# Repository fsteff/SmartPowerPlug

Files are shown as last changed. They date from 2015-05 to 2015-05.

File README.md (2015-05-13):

# SmartPowerPlug
A Raspberry PI based power plug that measures the energy.
It is able to turn on/off the power if necessary, based on a shell script to be highly customizeable.

The webinterface displays the measured values on an interactive graph (using Rickshaw).

------------------------------------------------------------------------
SOFTWARE:
------------------------------------------------------------------------
Needed programs:
 - Apache 2 (or a similar webserver)
 - php5 and php-cli
 - php5-sqlite
 - SQLite3

PHP Dependencies:
 - PhpSerial
 - System_Daemon
 
JS Dependencies:
 - Rickshaw
 - D3
 - JQuery
 - JQuery UI
 - Menumaker

All the dependencies are included in the source.

------------------------------------------------------------------------
HARDWARE:
------------------------------------------------------------------------
The energy measurement is based on the MCP39F501, which communciates over RS485.

------------------------------------------------------------------------
Known issues:
------------------------------------------------------------------------
- After a reboot the serial (uart) has to be opened by an other program - if this is not the case, the raspberry answers with some rubbish sequences...
- The calibration of the MCP39F501 is invalid - maybe there is a problem with the print.

You can download a preinstalled raspbian image here:
https://mega.co.nz/#F!rpBVlAKI!rYRUqPWmyS1goKNWMSgLuQ

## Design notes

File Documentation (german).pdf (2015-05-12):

Höhere Technische Bundeslehranstalt Steyr
Schlüsselhofgasse 63
4400 Steyr / Austria
Elektronik und Technische Informatik
+43 7252 72914 • www.htl-steyr.ac.at • office@htl-steyr.ac.at

# Smart Plug

Die intelligente Steckdose

## 1. Inhaltsverzeichnis

Elektronik und Technische Informatik
+43 7252 72914 • www.htl-steyr.ac.at • office@htl-steyr.ac.at

## 2. Angabe

Die intelligente Steckdose dient dazu, Strom zu sparen und somit den Stromverbrauch zu senken. Ziel ist es, den Benutzer die einzelnen Stromfresser bzw. den Stromverbrauch der angeschlossenen Geräte zu messen und anzuzeigen.
Die graphische Auswertung soll mithilfe eines Raspberry Pi durchgeführt werden.
Des Weiteren sollen die Messwerte in einem Diagramm auf einem Webserver abrufbar sein.
Um den Standby-Verbrauch zu senken müssen die Steckdosen abschaltbar sein.
Die Abschaltung der einzelnen Steckdosen muss individuell Ansteuerbar sein und über den Webserver Programmierbar sein.

## 3. Hardware

## 3.1. Blockschaltbild

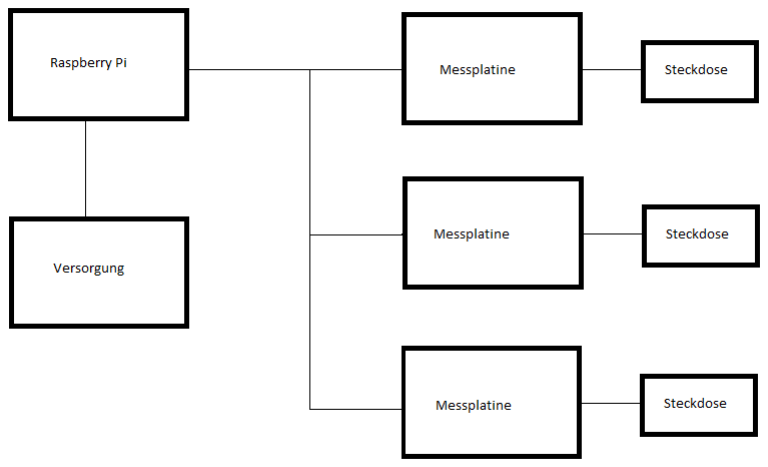
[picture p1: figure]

## 3.2. Messplatine

## 3.3. MCP39F501

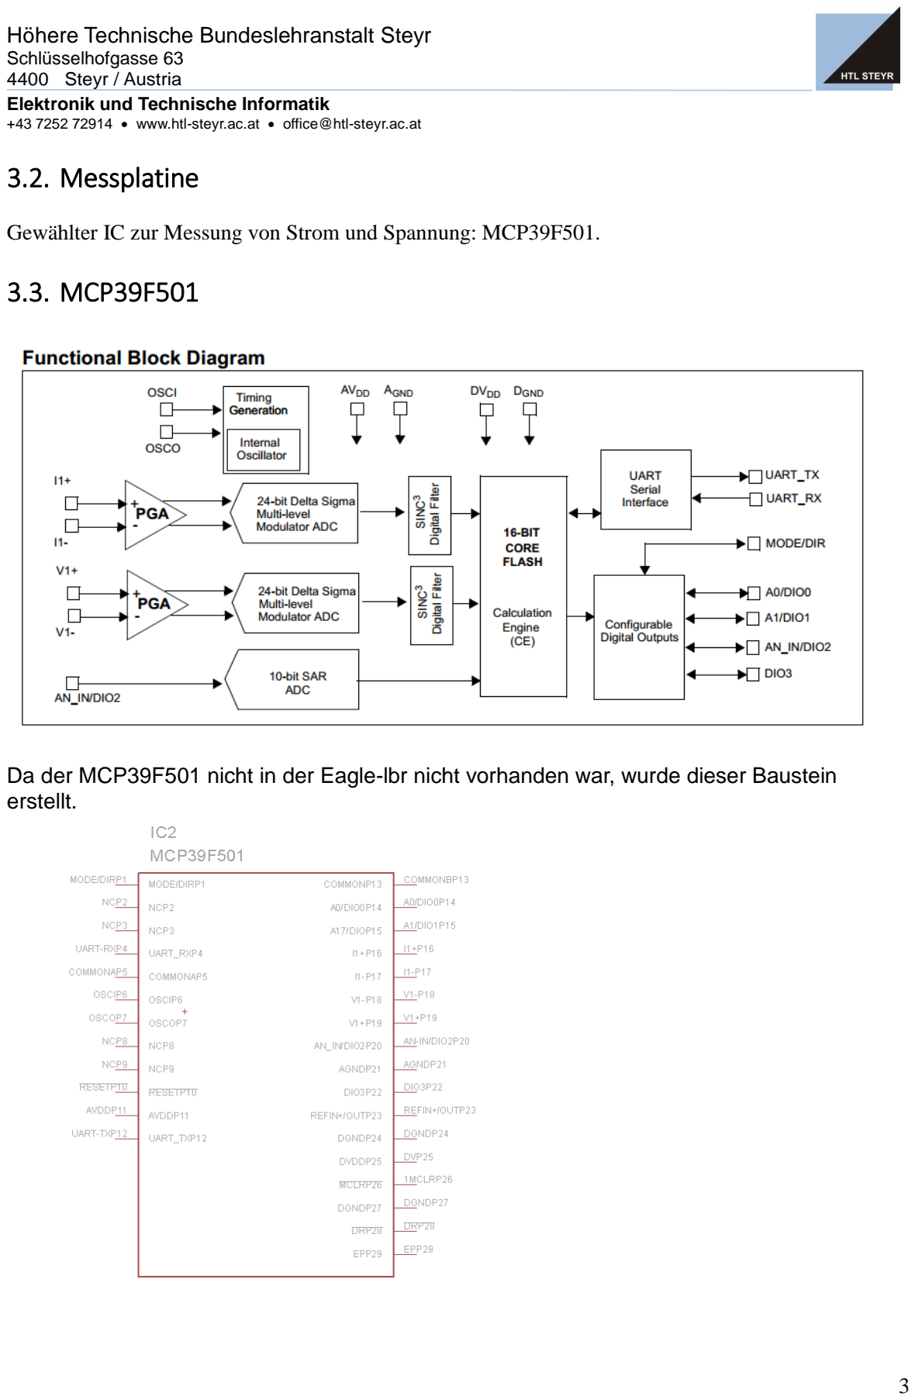
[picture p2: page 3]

Elektronik und Technische Informatik
+43 7252 72914 • www.htl-steyr.ac.at • office@htl-steyr.ac.at

Gewählter IC zur Messung von Strom und Spannung: MCP39F501.

Da der MCP39F501 nicht in der Eagle-lbr nicht vorhanden war, wurde dieser Baustein erstellt.

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

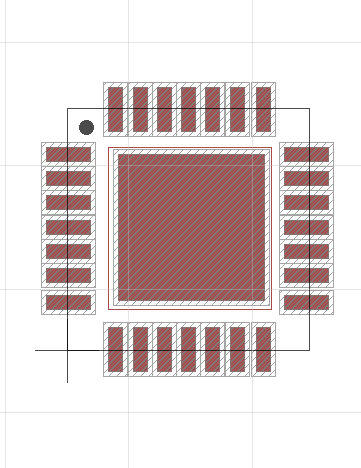
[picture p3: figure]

MCP39F501 wurde mithilfe des Datenblattes von Microchip erstellt.

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

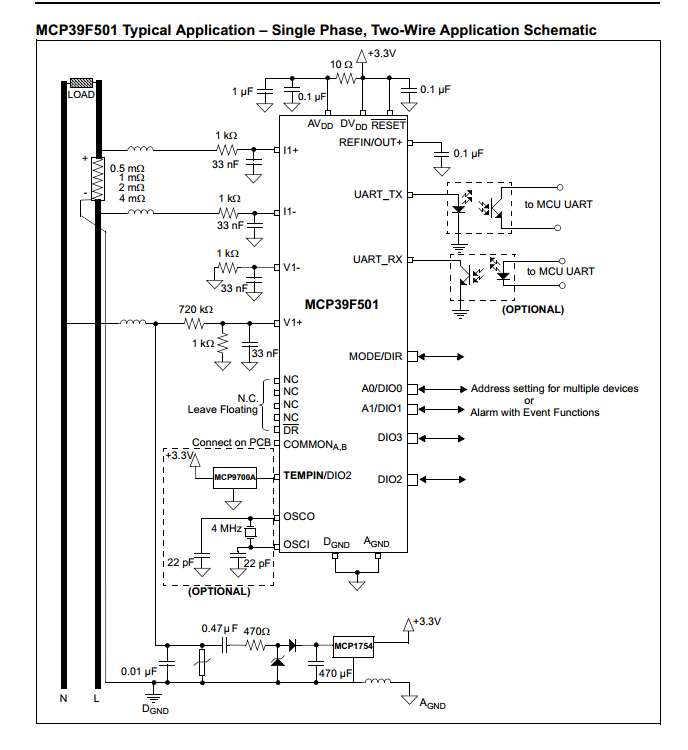
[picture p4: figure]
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

## 3.4. Schaltplan

Als Vorlage für den Schaltplan dient das Development Board von Microchip.

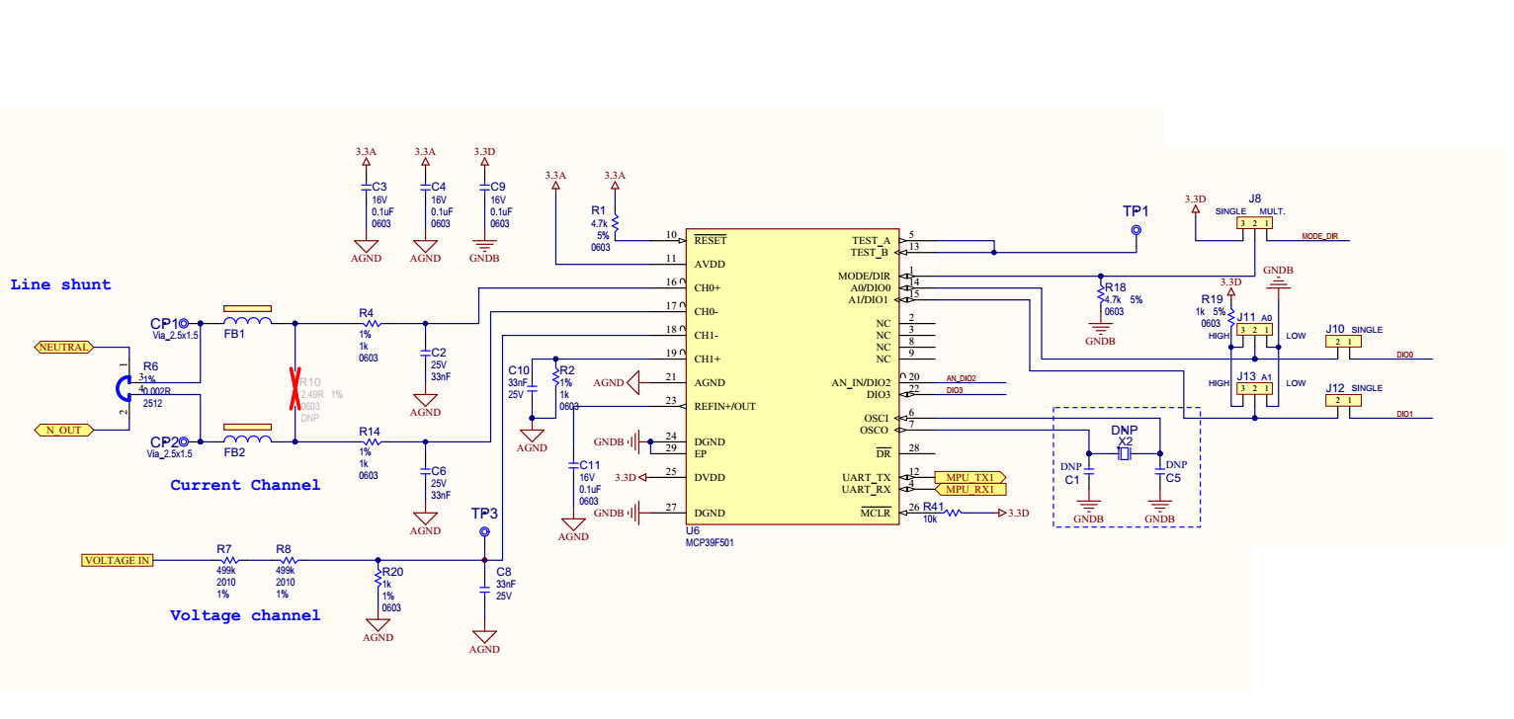
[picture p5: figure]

Jedoch wurde kein externer Oszillator verwendet. Des Weiteren sind die Pins 12 (UART_TX) und Pin 4 (UART_RX) auf einen MAX489CSD geführt. Der MAX489CSD wandelt das UART-Signal für einen RS485-Bus um. Somit ist es möglich, dass der RPI vier Steckdosen messen bzw. auswerten kann. Die Zahl vier ergibt sich daraus, dass der RPI zwei Pins zur Adressierung zur Verfügung stellt (Pin 14,15).

Für den Prototypenaufbau wurde der MODE/DIR-Pin, wie im Schaltplan auf einen Jumper geführt, um ihn messen zu können. Die Bauteilwerte wurden 1:1 vom Development Board übernommen.

Um die Spannung an der Steckdose ein bzw. auszuschalten wird ein Monostabiles Relais verwendet. Ein Monostabiles Relais wurde gewählt, da bei Spannungslosem Zustand das Relais offen ist. -> Steckdose Spannungsfrei bzw. Default Wert.
Die Ausgangsspannung eines GPIO beträgt 3,3V (HIGH-Zustand). Jedoch benötigt das Relais 12V für die Ansteuerung. -> Transistor als Schalter -> gewählt: BC517

Die Schaltpläne wurden in „Eagle V6.5.0“ gezeichnet und geroutet.

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

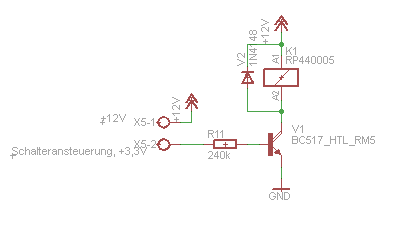
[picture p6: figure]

Die Diode dient als Freilaufdiode. -> Induktive Last

## 3.5. Kommunikation

RS485-Bussystem wurde gewählt, da dieser mehrerer Geräte unterstützt.
Für die Kommunikation werden die Pins MODE/DIR; UART_TX und UART_RX benötigt.

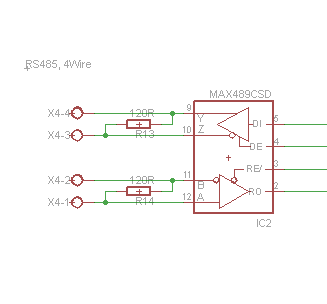
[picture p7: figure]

Anschlussbelegung:
MAX489CSD | MCP39F501
Pin 5 | UART_TX
Pin 4 | MODE/DIR
Pin 3 | MODE/DIR
Pin 2 | UART_RX

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

### 3.5.1. MODE/DIR

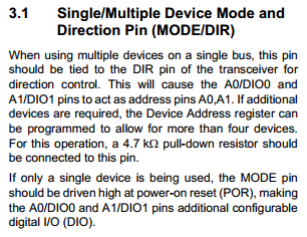
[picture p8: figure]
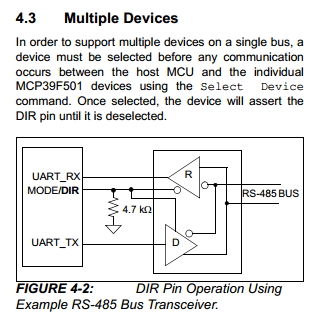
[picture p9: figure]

3.5.2. RS485

Es wird ein 4-Draht RS485-Bus verwendet, damit alle MCP39F501 die Informationen bzw. Befehle empfangen können. Dennoch antwortet nur der IC, welcher mit der gesendeten Adresse übereinstimmt. -> RPI ist Master, Slave sind MCP39F501

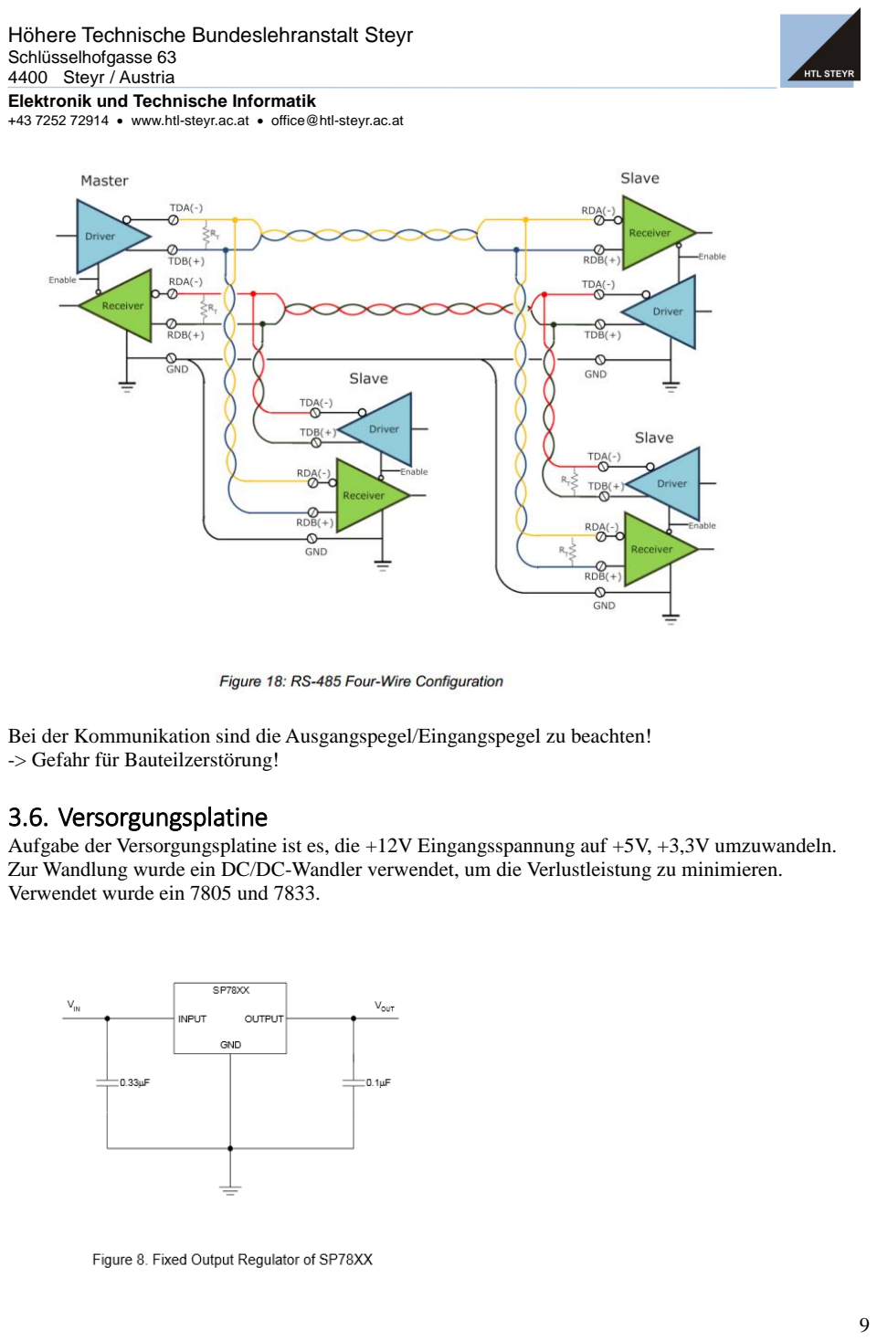
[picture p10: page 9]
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

Bei der Kommunikation sind die Ausgangspegel/Eingangspegel zu beachten! -> Gefahr für Bauteilzerstörung!

## 3.6. Versorgungsplatine

Aufgabe der Versorgungsplatine ist es, die +12V Eingangsspannung auf +5V, +3,3V umzuwandeln. Zur Wandlung wurde ein DC/DC-Wandler verwendet, um die Verlustleistung zu minimieren. Verwendet wurde ein 7805 und 7833.

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

Weiteres befindet sich ein MAX489CSD auf der Platine.

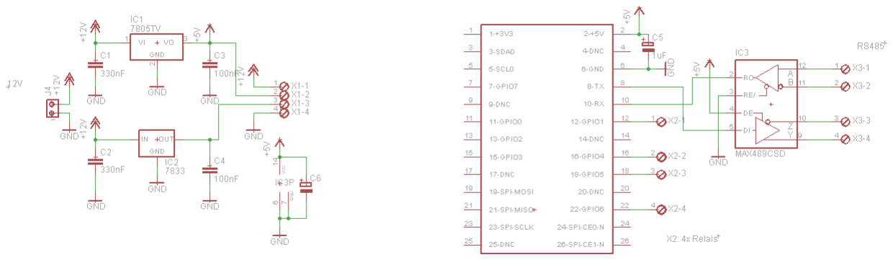
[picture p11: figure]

Die Eingänge DE und RE vom MAX489 wurden auf Masse bzw. High geschaltet, um konstant lesen und schreiben zu können.

## 3.7. Programmierung des MCP39F501

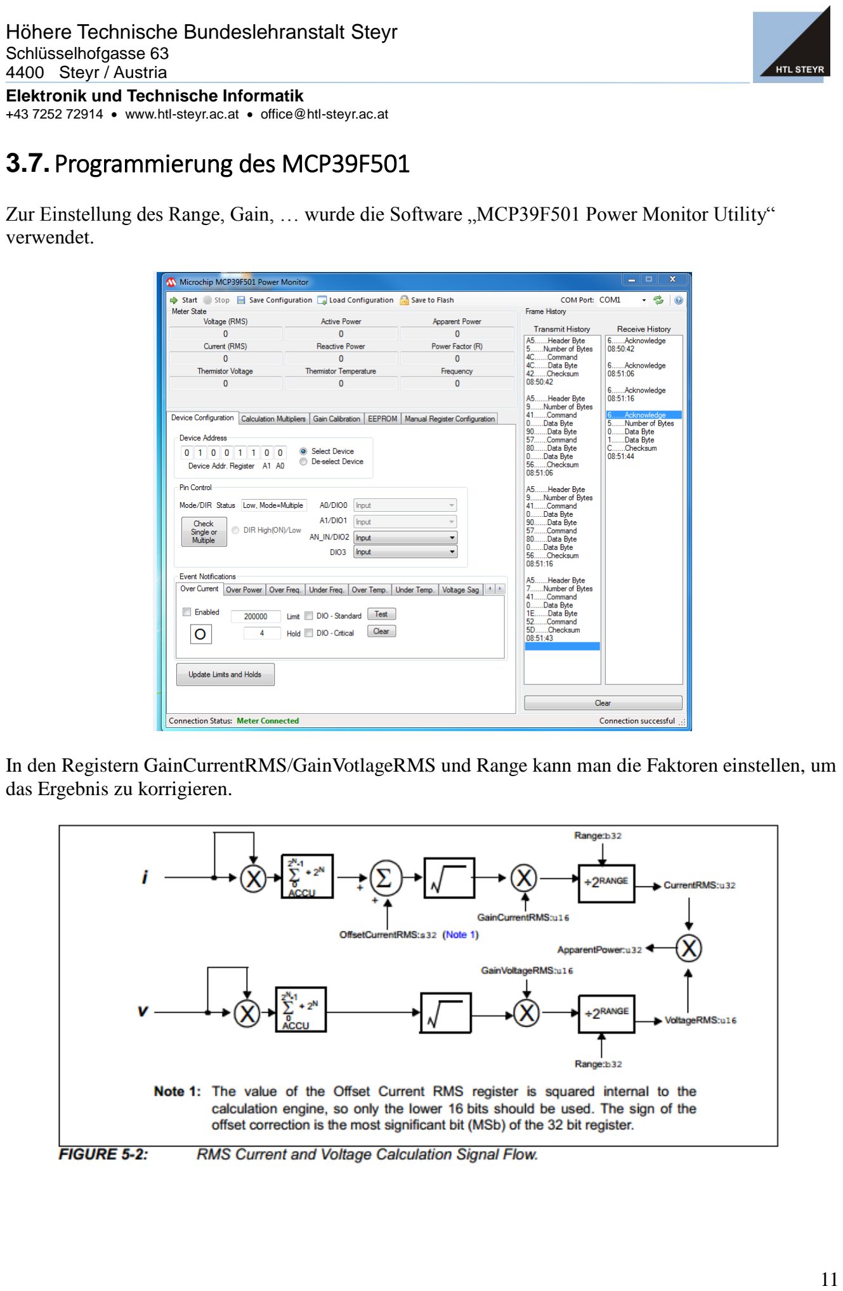
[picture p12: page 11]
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

Zur Einstellung des Range, Gain, … wurde die Software „MCP39F501 Power Monitor Utility“ verwendet.

In den Registern GainCurrentRMS/GainVotlageRMS und Range kann man die Faktoren einstellen, um das Ergebnis zu korrigieren.

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

→ Geählter Wert für GainVoltageRMS: 6DD

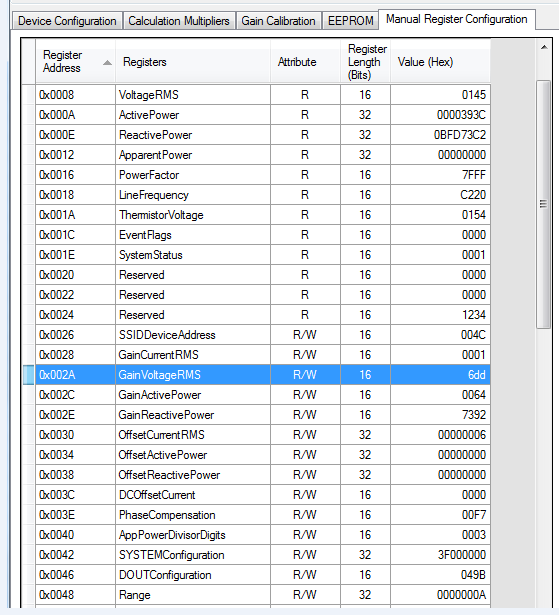
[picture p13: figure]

→ Gewählter Wert für Range: A

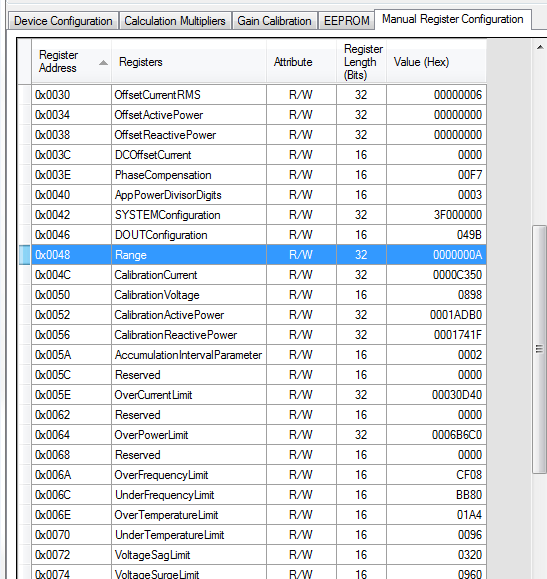
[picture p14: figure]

Als Last wurde eine Herdplatte verwendet (1800W).

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

### 3.7.1. Protokoll

z.B.:

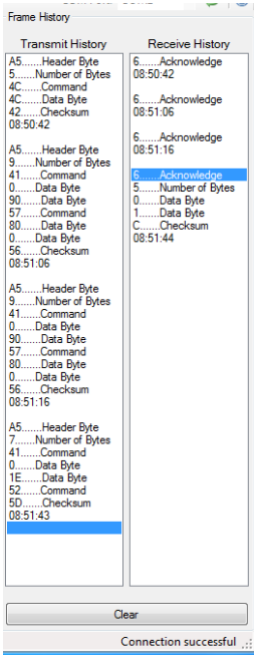
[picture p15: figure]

Weitere Informationen befinden sich im Datenblatt.

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

## 3.8. Bauteile

Name | Wert | Stück
C1-4 | 33n | 6
C5 | 0,01uF/ 10n | 3
R1 | 240k | 1
R2 | 4k7 | 1
R3,4,8,9 | 1k | 4
R5 | Shunt 0,025R | 1
R6,7 | 500k | 2
R10 | 10k | 1
R11 | 120R | 6
T1 | BC517 | 1
D1 | 1N4148 | 1
IC | MCP39F501 | 1
IC | MAX489CSD | 2
IC | 7805 | 1
IC | 7833 | 1
L | Ferrit bead 0805 Automotiv 150R R15 | 5
Relais | Monostabiles Relais 2-polig | 1

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

## 4. Software

## 4.1. Betriebssystem und installierte Programme/Bibliotheken

Das installierte Betriebssystem ist Raspbian, welches auf die Linux Distribution Debian Wheezy aufbaut.

### 4.1.1. Installierte Programme und Bibliotheken

- Apache 2 (v. 2.2.22)
Webserver für das Webinterface
- PHP und PHP-CLI(v. 5.4.35)
PHP Interpreter mit Kommandozeilen-Interface
- php5-sqlite
PHP-Erweiterung um mit SQLite zu kommunizieren
- SQLite3 (v. 3.7.13)
Einfache, sehr Ressourcen-schonende Datenbank
- PEAR und PEAR-Packages

### 4.1.2. Verwendete, jedoch nicht installierte Bibliotheken

PHP:
- PhpSerial
Vereinfacht die Benutzung einer Seriellen Schnittstelle in PHP
- System_Daemon
Ermöglicht das starten eines PHP-CLI Programms als Daemon (Service) (installiert über PEAR)
Javascript:
- Rickshaw
Eine Bibliothek zum einfachen Zeichnen von Graphen
- D3
Grafik-Bibliothek, auf die Rickshaw aufgebaut ist
- JQuery
Bibliothek zum einfachen und schnellen Bearbeiten des Webseiten-Inhalts
- JQuery UI
Moderne und einfach benutzbare Benutzeroberflächen-Werkzeuge
- Menumaker
Zum schnellen Erstellen von modernen Menüleisten

## 4.2. Funktionsprinzip

Grundsätzlich besteht das Programm aus 2 Teilen:
- Der SmartPlug Service ist ein im Hintergrund laufendes Programm, das den Großteil der Funktionalität bereitstellt.
Die Konfiguration wird in eine Datei geschrieben, wobei diese jederzeit geändert werden kann und automatisch übernommen wird.
Zum Prüfen, ob eine Steckdose ein- oder ausgeschaltet werden soll wird ein Shell-Script aufgerufen, das bei Bedarf vom Benutzer ohne Neustart des Services bearbeitet werden kann.
- Das Webinterface bildet die Schnittstelle zum Benutzer. Es zeichnet den Stromverbrauch als

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

Graphen und ermöglicht das Konfigurieren über eine graphische Oberfläche.

### 4.2.1. Blockschaltbild

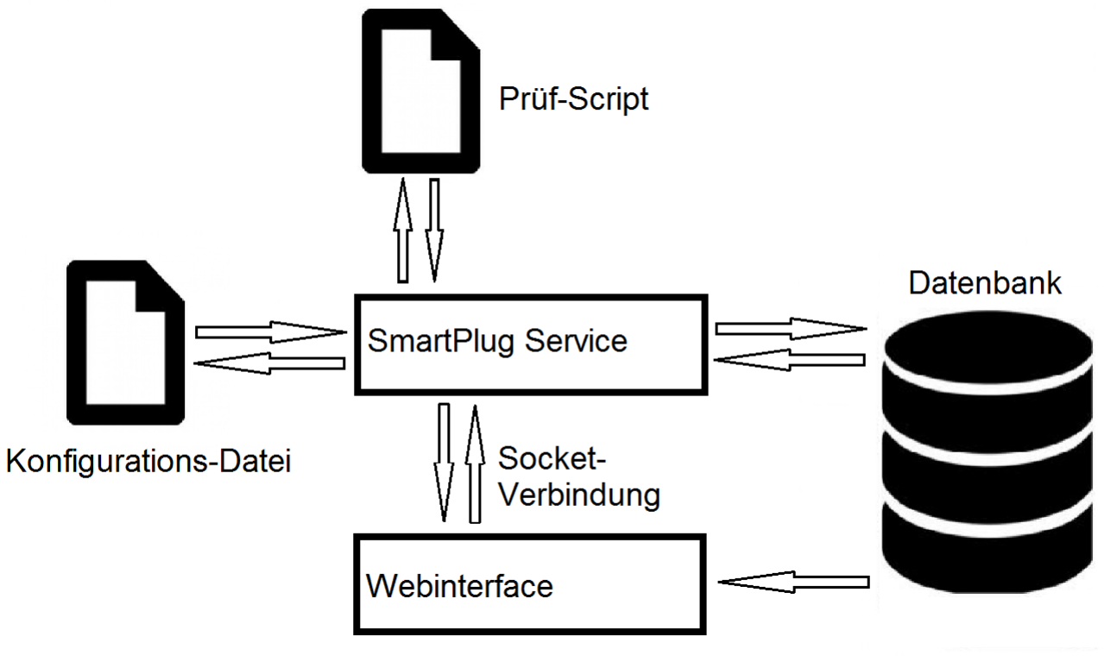
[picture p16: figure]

Abbildung 1Blockschaltbild Programme

## 4.3. SmartPlug Service

Nach dem Start des Services wird die run() – Funktion der Klasse MainLoop gestartet.
Diese hat intern eine Endlosschleife, die einmal pro Sekunde den Strom misst und in der Zwischenzeit Socket-Nachrichten behandelt, die gemessenen Werte analysiert und speichert und prüft, ob eine der Steckdosen ein- oder ausgeschaltet werden soll.
Der Service besteht hautsächlich aus folgenden Klassen:
- DBManager
Ist für alle Datenbank-Operationen zuständig.
- Log
Schreibt Nachrichten mit weiteren Details, wie Zeit und aufrufender Klasse, versehen in die Log-Datei.
- AllRelaisConfigurations
Enthält die Konfiguration für alle vier Steckdosen / das Verhalten aller Relais. Die Klasse liest die Konfigurations-Datei ein und schreib Änderungen hinein.
- RelaisConfiguration
Enthält die Konfiguration für eine Steckdose / ein Relais.
- RelaisController
Startet den Prüf-Script (abhängig von der Konfiguration) und wertet die Ergebnisse aus.
- MeasureValue
Speichert einen Messwert. Es wird das letzte Minimum, Maximum, der Durchschnitt und der letzte Wert gespeichert. Außerdem wird eruiert, ob die Wertänderung seit der letzten Abfrage

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

innerhalb einer definierten Toleranz ist.
- MeasureDevice
Enthält je eine Instanz von MeasureValue für jeden Wert, der gemessen wird.
- Measurement
Ist für die Kommunikation mit dem Strommess-Chip zuständig.
- Serial
Ist eine Wrapper-Klasse für die PhpSerial – Bibliothek.
- Socket
Beinhaltet einen Server-Socket und wertet die Nachrichten nach einem eigenen Protokoll aus.
- GPIO
Erleichtert das Schreiben auf und das Auslesen von GPIOs.

## 4.4. Datenbank

Die Datenbank besteht aus drei identischen Tabellen:
- DayMeasurements
Hier werden die Messwerte im 5-Minuten-Takt gespeichert.
- MonthMeasurements
Hier werden die Messwerte im 1-Stunden-Takt gespeichert.
- YearMeasurements
Hier werden die Messwerte einmal pro Tag gespeichert.

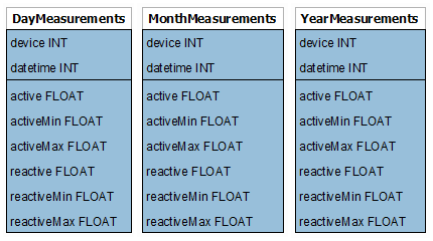
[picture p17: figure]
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

## 4.5. Webinterface

Das Webinterface zeichnet Graphen für die Tages-, Monats- und Jahresmessewerte für jedes Gerät einzeln.
Außerdem ist es möglich das Schaltverhalten der Relais per grafischer Oberfläche zu konfigurieren. Die Funktionalität bieten folgende PHP-Klassen:
- CMS
Ist für das Erstellen des HTML-Headers und Bodys zuständig.
- Chart
Bindet die JS-Bibliothek Rickshaw ein.
- DBManager
Ist die Webserver-seitige Anbindung an die Datenbank.
- SocketClient
Bildet das Gegenstück der Klasse Socket im SmartPlug Service. Es gibt folgende Seiten:
- index.php zeigt die Graphen.
- settings.php bietet die Funktionalität mit der Konfiguration.
Um diese Seite aufzurufen, muss der Service laufen, da die Konfiguration über die Socket-Verbindung abgefragt wird.
- data.php ist eine Seite, die nur für den Gebrauch mit AJAX gedacht ist und die Messwerte im JSON-Format ausgibt.

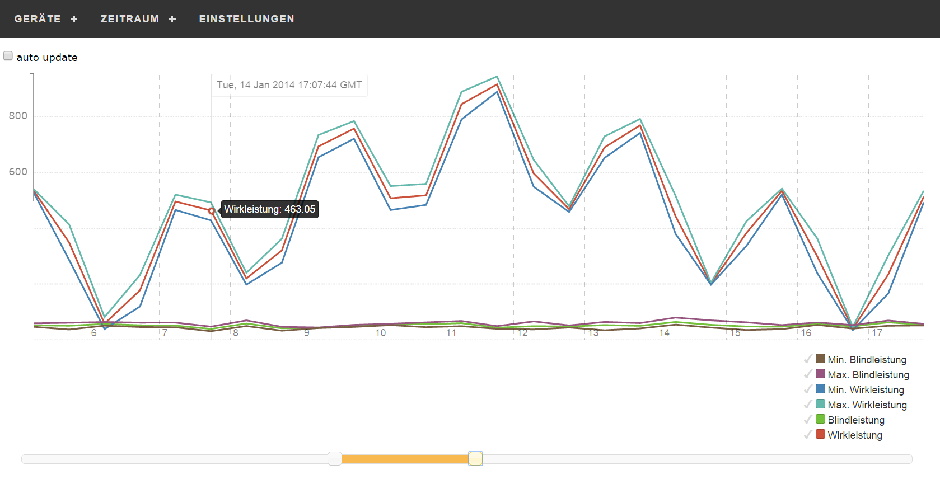
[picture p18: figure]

Abbildung 2: index.php

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

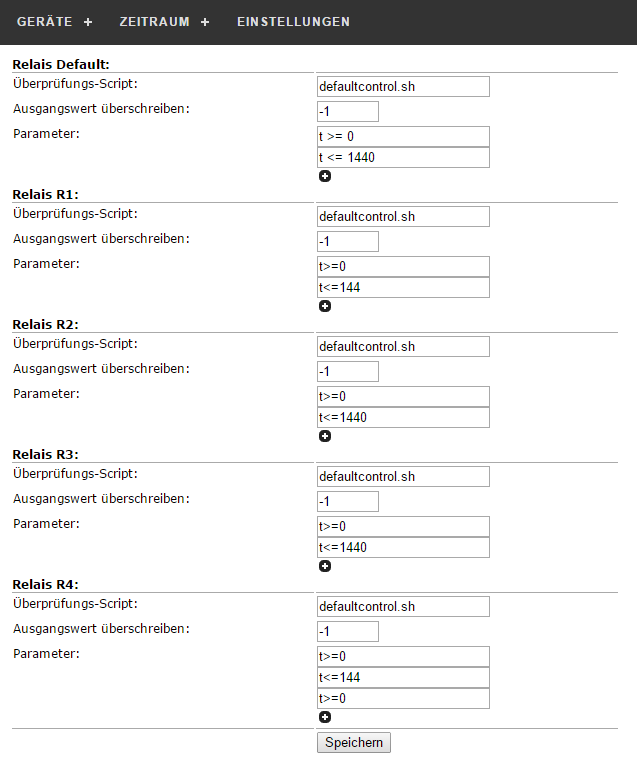
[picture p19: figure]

Abbildung 3: settings.php

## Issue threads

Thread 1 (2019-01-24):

MCP39F501 using MCP2200

VictorTagayun, 2019-01-24:
Hello, Did you happen to use the demo board with MCP2200 USB to Serial?
I want to connect the Raspberry to this demo board and want to display the power.

fsteff, 2019-01-24:
No, we created our own board and the communication took place over the RPI's GPIOs.
However, we had difficulties with the MCP39F501 - it did not measure correct values and we were not able to find the problem until the end of the project.

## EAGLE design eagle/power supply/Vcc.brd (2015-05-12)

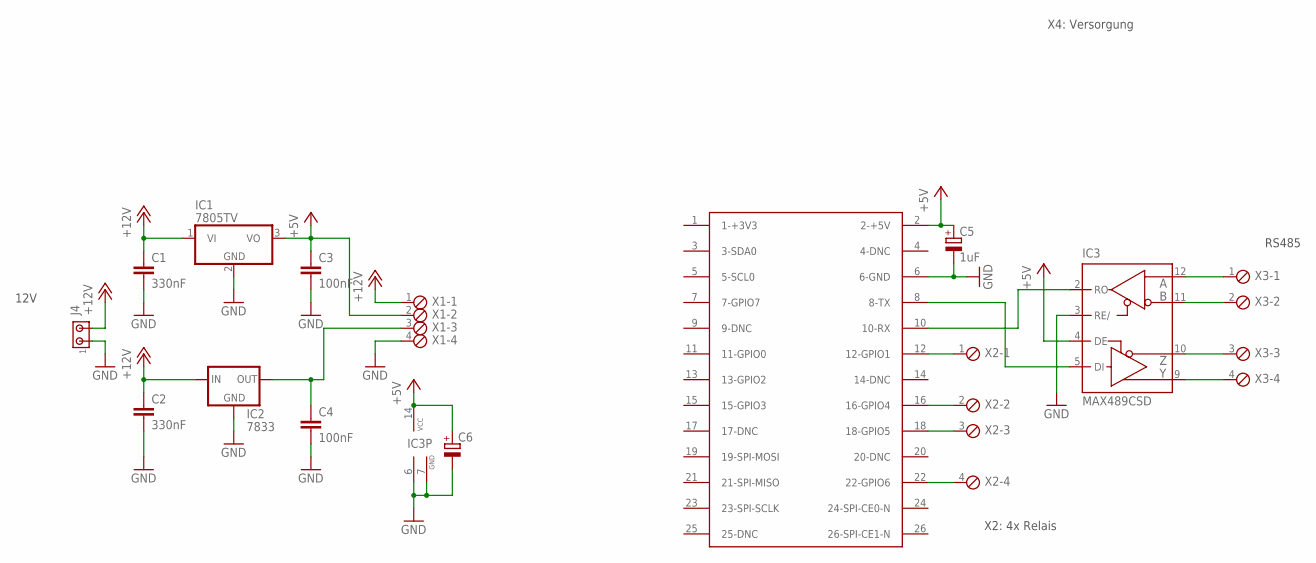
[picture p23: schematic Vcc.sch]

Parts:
C1, C2: 330nF; C050-035X075
C3, C4: 100nF; C050-035X075
C5: 1uF; E2,5-7
C6: CPOL-EUE2.5-7; E2,5-7
IC1: 7805TV; TO220V
IC2: 7833; 78XXS
IC3: MAX489CSD; SO14
J4: MTA02-100; 10X02MTA
U$1: RASPBERRY-PI
X1, X2, X3: MPT4; 4POL254

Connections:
+5V: C3.1, C5.+, C6.+, IC1.3 (VO), IC3.4 (DE), IC3.14 (VCC), U$1.2 (2-+5V), X1.2
+12V: C1.1, C2.1, IC1.1 (VI), IC2.IN, J4.2, X1.1
GND: C1.2, C2.2, C3.2, C4.2, C5.-, C6.-, IC1.2 (GND), IC2.GND, IC3.3 (RE/), IC3.6 (GND), IC3.7 (GND), J4.1, U$1.6 (6-GND), X1.4
unnamed: U$1.18 (18-GPIO5), X2.3
unnamed: U$1.22 (22-GPIO6), X2.4
unnamed: IC3.11 (B), X3.2
unnamed: IC3.2 (RO), U$1.10 (10-RX)
unnamed: IC3.5 (DI), U$1.8 (8-TX)
unnamed: IC3.9 (Y), X3.4
unnamed: IC3.10 (Z), X3.3
unnamed: IC3.12 (A), X3.1
unnamed: U$1.16 (16-GPIO4), X2.2
unnamed: C4.1, IC2.OUT, X1.3
unnamed: U$1.12 (12-GPIO1), X2.1

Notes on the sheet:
12V
X2: 4x Relais
X4: Versorgung
RS485

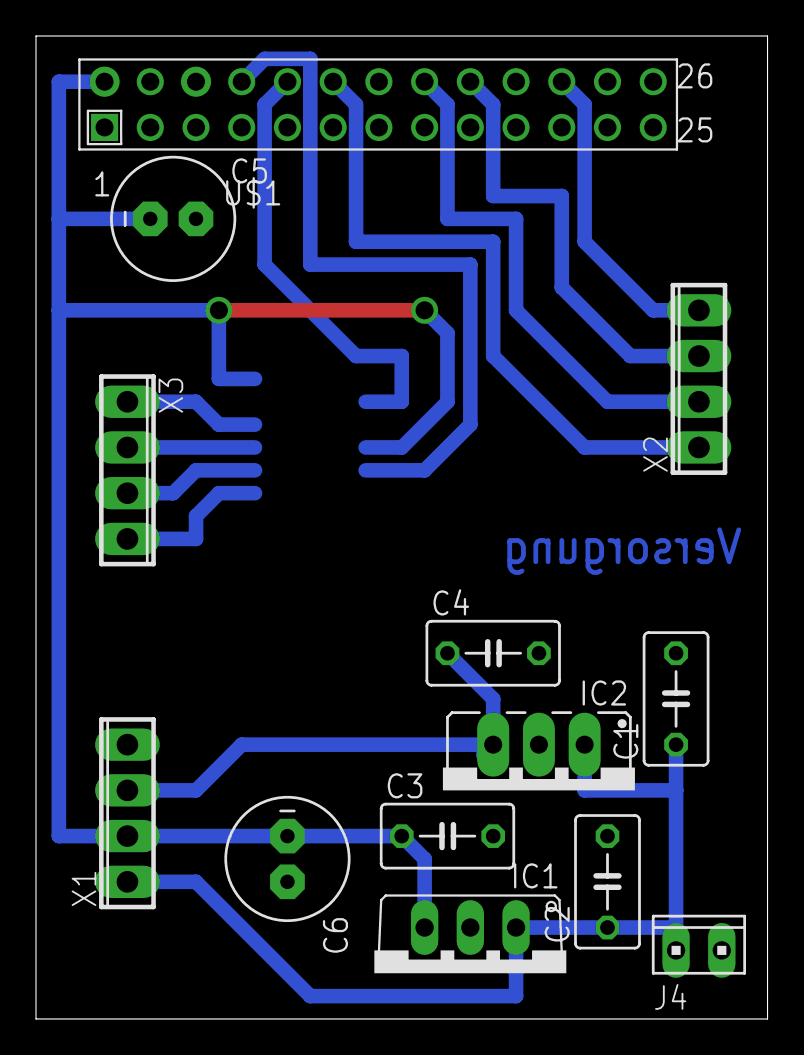
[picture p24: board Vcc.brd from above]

Board: 2 copper layers, 40.6 x 54.6 mm, 14 parts (1 on the bottom side), 14 nets.

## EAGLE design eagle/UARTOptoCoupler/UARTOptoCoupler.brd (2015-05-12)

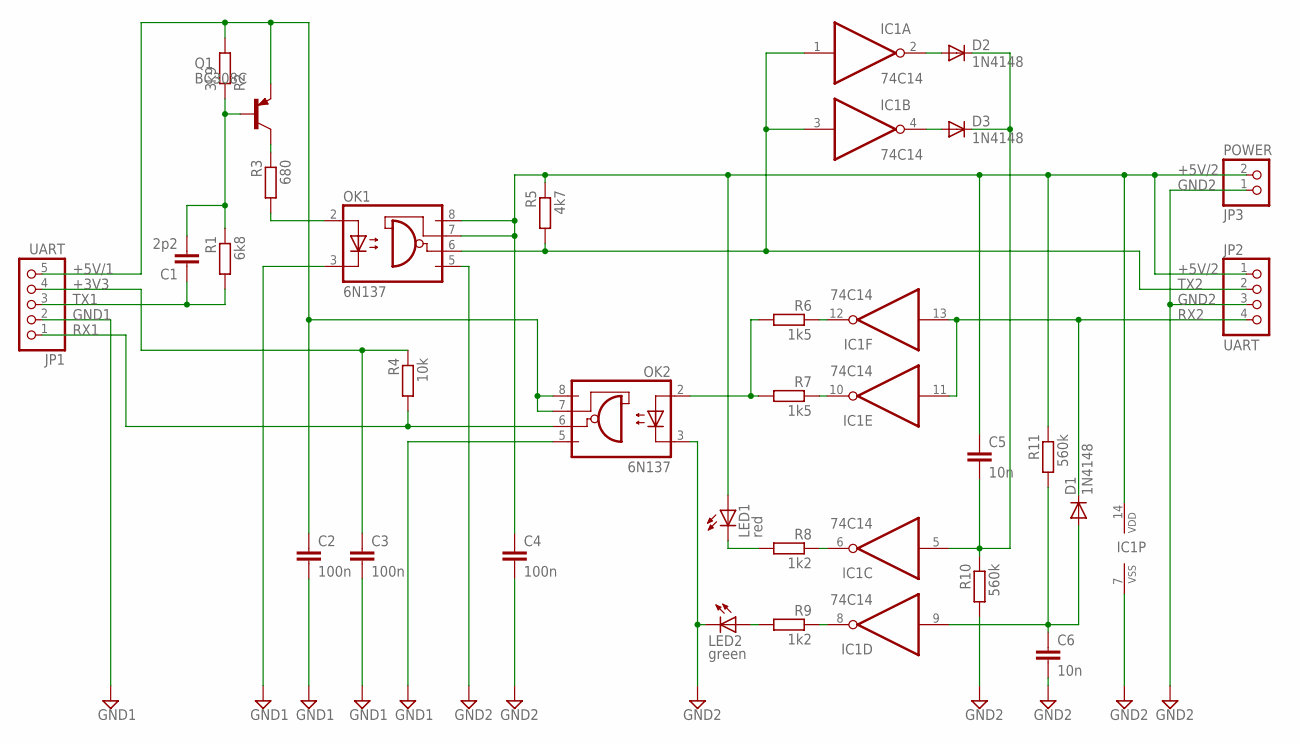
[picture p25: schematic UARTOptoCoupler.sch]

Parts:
C1: 2p2; C025-024X044
C2, C3, C4: 100n; C050-025X075
C5, C6: 10n; C050-025X075
D1, D2, D3: 1N4148; DO35-10
IC1: 74C14; DIL14
JP1: UART; 1X05
JP2: UART; 1X04/90
JP3: POWER; 1X02
LED1: red; LED3MM
LED2: green; LED3MM
OK1, OK2: 6N137; DIL08
Q1: BC308C; TO92
R1: 6k8; 0207/10
R2: 3k9; 0207/10
R3: 680; 0207/10
R4: 10k; 0207/10
R5: 4k7; 0207/10
R6, R7: 1k5; 0207/10
R8, R9: 1k2; 0207/10
R10, R11: 560k; 0207/10

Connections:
+3V3: C3.1, JP1.4, R4.1
+5V/1: C2.1, JP1.5, OK2.7 (VE), OK2.8 (VCC), Q1.1 (E), R2.2
+5V/2: C4.1, C5.1, IC1.14 (VDD), JP2.1, JP3.2, LED1.A, OK1.7 (VE), OK1.8 (VCC), R5.1, R11.1
GND1: C2.2, C3.2, JP1.2, OK1.3 (C), OK2.5 (GND)
GND2: C4.2, C6.2, IC1.7 (VSS), JP2.3, JP3.1, LED2.K (C), OK1.5 (GND), OK2.3 (C), R10.2
N1: C1.2, Q1.2 (B), R1.1, R2.1
unnamed: OK1.2 (A), R3.2
unnamed: LED1.K (C), R8.2
unnamed: Q1.3 (C), R3.1
unnamed: OK2.2 (A), R6.2, R7.2
unnamed: C5.2, D2.C, D3.C, IC1.5 (I), R10.1
unnamed: IC1.12 (O), R6.1
unnamed: IC1.10 (O), R7.1
unnamed: C6.1, D1.A, IC1.9 (I), R11.2
unnamed: IC1.6 (O), R8.1
unnamed: IC1.8 (O), R9.1
unnamed: D3.A, IC1.4 (O)
unnamed: LED2.A, R9.2
unnamed: D2.A, IC1.2 (O)
RX1: JP1.1, OK2.6 (VO), R4.2
RX2: D1.C, IC1.11 (I), IC1.13 (I), JP2.4
TX1: C1.1, JP1.3, R1.2
TX2: IC1.1 (I), IC1.3 (I), JP2.2, OK1.6 (VO), R5.2

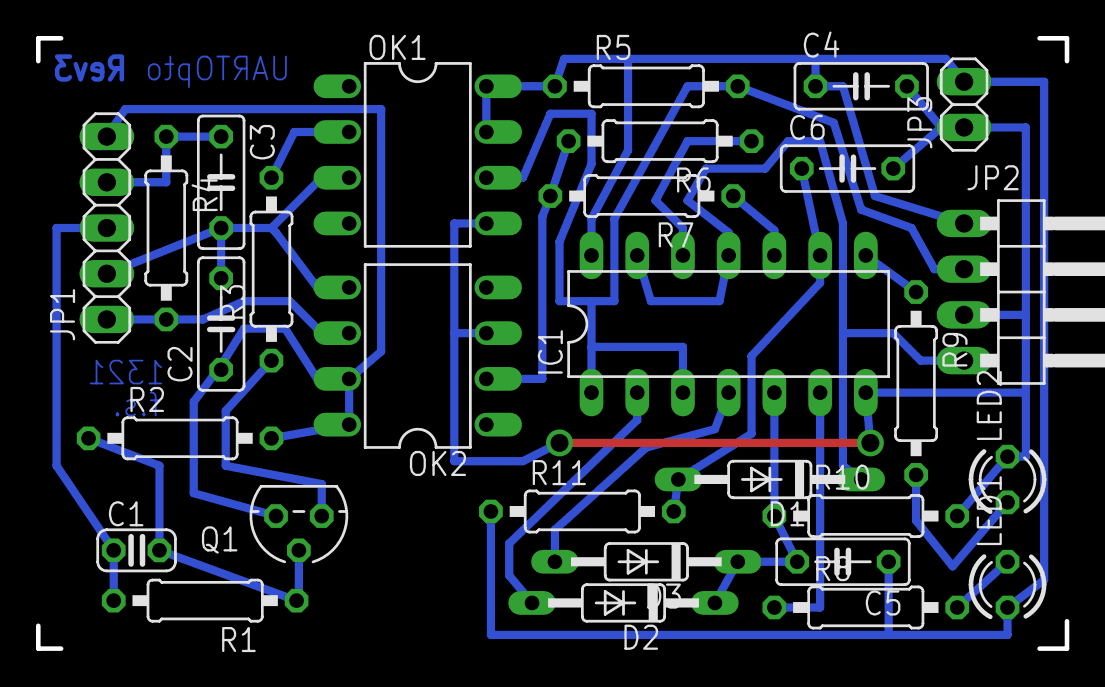
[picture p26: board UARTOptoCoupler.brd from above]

Board: 2 copper layers, 57.1 x 33.9 mm, 29 parts (0 on the bottom side), 23 nets.

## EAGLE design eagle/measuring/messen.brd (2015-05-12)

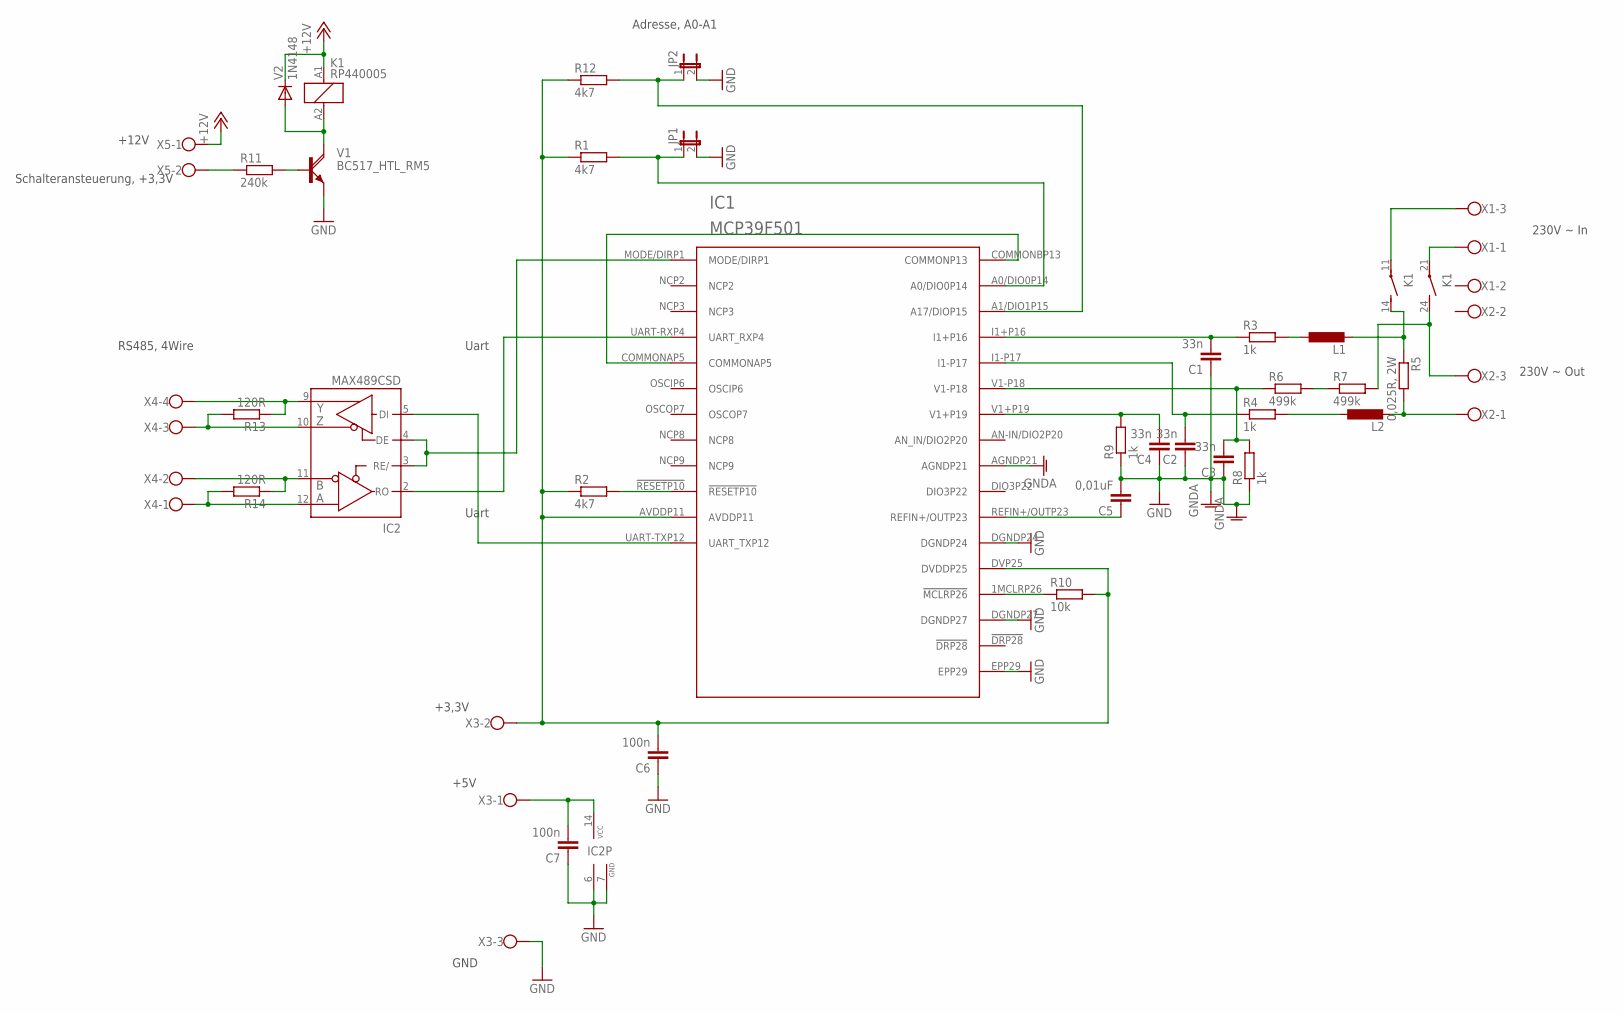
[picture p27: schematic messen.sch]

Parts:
C1, C2, C3, C4: 33n; C0805K
C5: 0,01uF; C0805K
C6, C7: 100n; C0805K
IC1: MCP39F501
IC2: MAX489CSD; SO14
JP1, JP2: JP1E; JP1
K1: RP440005; RP440
L1, L2: L-EUL3230M; L3230M
R1, R12: 4k7; R0805
R2: 4k7; 0411/15
R3, R4, R8, R9: 1k; R0805
R5: 0,025R, 2W; R2512
R6, R7: 499k; 0411/15
R10: 10k; 0204/7
R11: 240k; 0411/15
R13, R14: 120R; R0805
V1: BC517_HTL_RM5; TO92_RM5
V2: 1N4148; DO35-7
X1, X2: W237-103_R
X3: W237-103_L
X4: W237-04P_L; W237-4P_L
X5: W237-102_L

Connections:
+12V: K1.A1 (1), V2.C, X5.1
GND: C1.1, C2.1, C3.1, C4.1, C5.2, C6.1, C7.1, IC1.AGNDP21, IC1.DGNDP24, IC1.DGNDP27, IC1.EPP29, IC2.6 (GND), IC2.7 (GND), JP1.2, JP2.2, R8.1, R9.1, V1.1 (E), X3.3
unnamed: R11.1, X5.2
unnamed: IC1.UART-RXP4 (UART_RXP4), IC2.2 (RO)
unnamed: IC1.MODE/DIRP1, IC2.3 (RE/), IC2.4 (DE)
unnamed: IC1.!RESETP10, R2.2
unnamed: C1.2, IC1.I1+P16, R3.1
unnamed: C2.2, IC1.I1-P17, R4.1
unnamed: C4.2, IC1.V1+P19, R9.2
unnamed: K1.A2 (2), V1.3 (C), V2.A
unnamed: L1.1, R3.2
unnamed: L2.1, R4.2
unnamed: L2.2, R5.2, X2.1
unnamed: K1.11, X1.3
unnamed: C5.1, IC1.REFIN+/OUTP23
unnamed: C3.2, IC1.V1-P18, R6.1, R8.2
unnamed: C6.2, IC1.AVDDP11, IC1.DVP25 (DVDDP25), R1.1, R2.1, R10.2, R12.1, X3.2
unnamed: IC1.1MCLRP26 (!MCLRP26), R10.1
unnamed: R11.2, V1.2 (B)
unnamed: R6.2, R7.1
unnamed: K1.14 (S), L1.2, R5.1
unnamed: K1.24 (S), R7.2, X2.3
unnamed: K1.21, X1.1
unnamed: IC1.UART-TXP12 (UART_TXP12), IC2.5 (DI)
unnamed: C7.2, IC2.14 (VCC), X3.1
unnamed: IC1.COMMONAP5, IC1.COMMONBP13 (COMMONP13)
unnamed: IC2.10 (Z), R13.2, X4.3
unnamed: IC2.9 (Y), R13.1, X4.4
unnamed: IC1.A0/DIO0P14, JP1.1, R1.2
unnamed: IC1.A1/DIO1P15 (A17/DIOP15), JP2.1, R12.2
unnamed: IC2.11 (B), R14.1, X4.2
unnamed: IC2.12 (A), R14.2, X4.1

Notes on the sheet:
230V ~ Out
230V ~ In
Adresse, A0-A1
+3,3V
GND
Uart
+5V
RS485, 4Wire
Schalteransteuerung, +3,3V
+12V

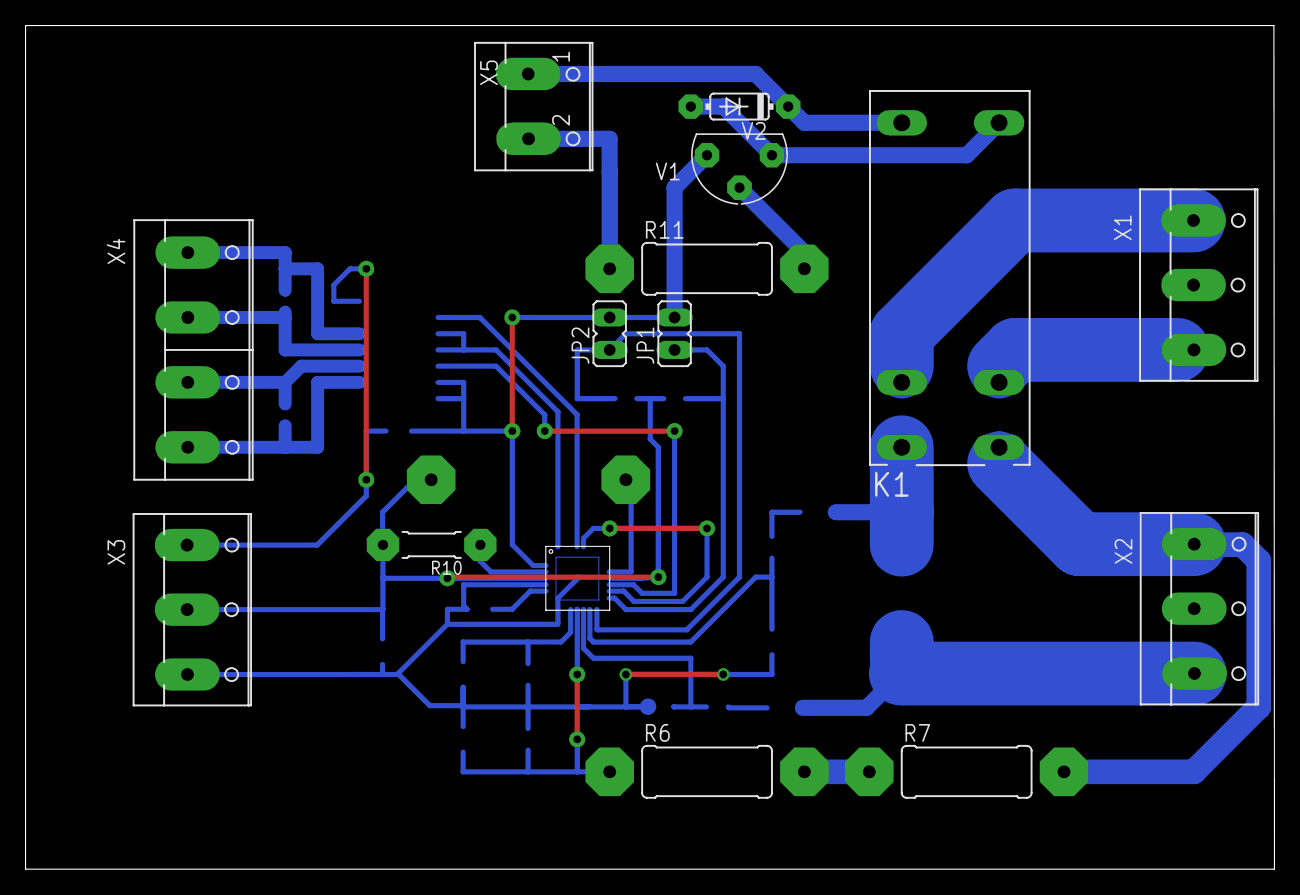
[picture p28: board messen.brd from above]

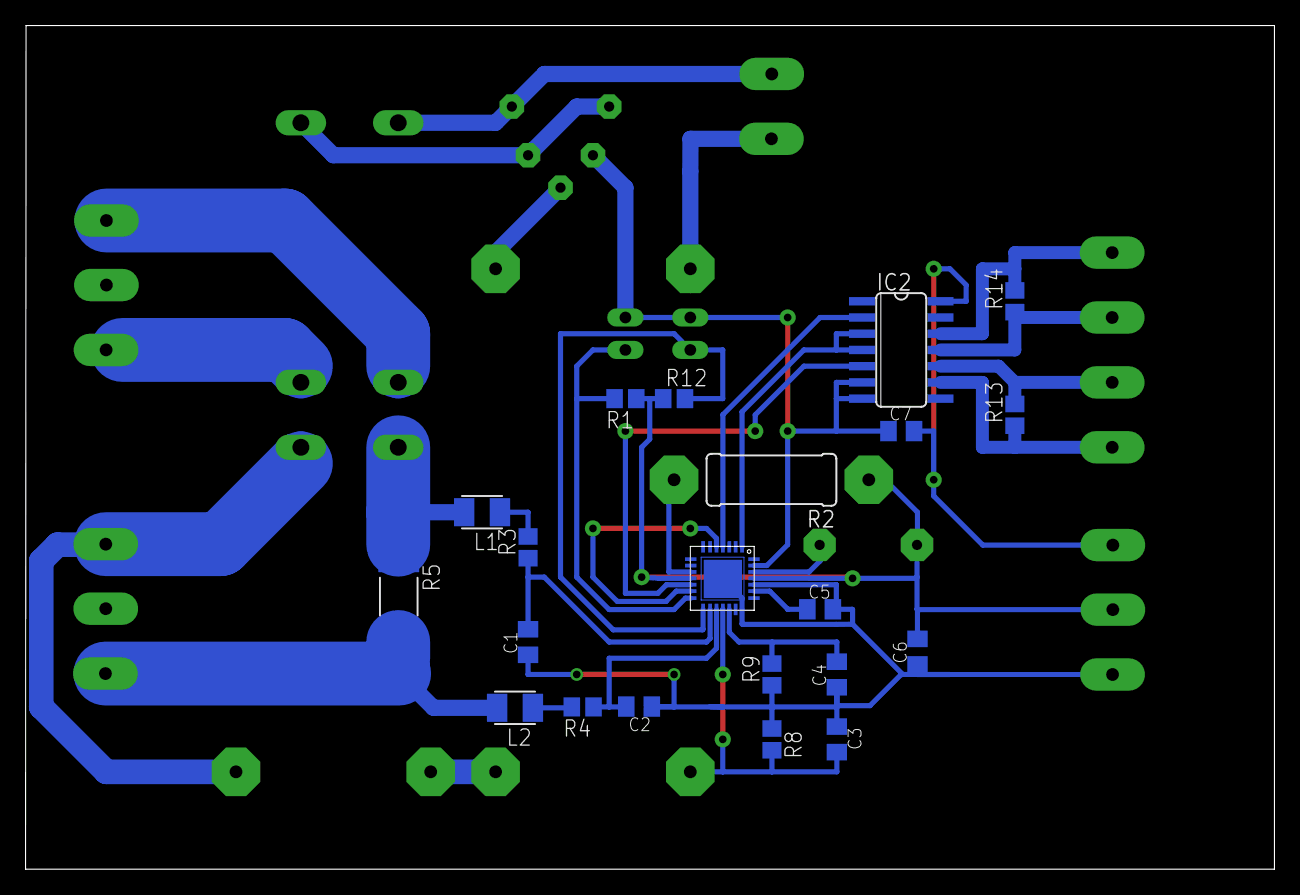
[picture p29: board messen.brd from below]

Board: 2 copper layers, 97.8 x 66.0 mm, 35 parts (21 on the bottom side), 32 nets.
